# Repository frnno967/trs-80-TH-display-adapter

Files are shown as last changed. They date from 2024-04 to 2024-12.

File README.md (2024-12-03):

# Digital Video Display Adapter for the TRS-80 Model 3 and Model 4
A through-hole remix of [Matt Boytim's TRS-80 FPGA Digital Video display adapter.](https://github.com/maboytim/TRS-80_Display_Adapter/tree/main) Created with EasyEDA.

This remix removes the unused VGA connections, adds some useful powering options, adds additional silkscreen descriptions, and uses all through-hole parts for ease of assembly by the hobbyist.



# Minimum Required parts:
* QTY 1 Tang Nano 9K FPGA board with headers and programmed with bitstream from above for the appropriate Model, either 3 or 4.
* QTY 2 24 Pin Female to Male 2.54mm headers for attaching Tang Nano 9K to the PCB
* QTY 2 2 Position Male to Male 2.54mm Pin Headers for use with J3 and J5
* QTY 1 3 Position Male to Male 2.54mm Pin Headers for use with H1
* QTY 3 2.54mm Jumper Shunts like TE Connectivity 2-881545-2
* QTY 1 Texas Instruments SN74LV125AN Quad Bus Buff Gate With 3-State Outputs, or equivalent for U1. 
* QTY 1 L7805 Linear Voltage Regulator, or equivalent DC/DC voltage converter regulator for U3
* QTY 1 10uF Capacitor, Radial Leads for C1
* QTY 2 1uF Capacitor, Radial Leads for C3 and C4
* QTY 1 0.1uF Capacitor, Radial Leads for C2
* QTY 2 Axial 1K Ohm 1/4 Watt Resistors for R6 and R7

Mouser Cart with all parts available here: https://www.mouser.com/ProjectManager/ProjectDetail.aspx?AccessID=4506e6a91b

# Additional Optional Parts:
* QTY 2 6 Position Male to Male 2.54mm Pin Headers for use with Video Input from Motherboard for direct connection without the CRT Harness, with pass-through connector option to continue using the harness and output adapter at the same time.
* QTY 1 16 Pin 2x8 Male to Male 2.54mm Pin Headers for use with J4 Option Jumpers for color settings
* QTY 1 Molex 22-05-1042 Male Right Angle 4 Pin Header for power via system power supply, or for use as pass-thru power. Do not operate power-hungry devices off of 5V output of this connector!

Special thanks to Matt Boytim and all of the TRS-80 community for creating awesome enhancements like these.

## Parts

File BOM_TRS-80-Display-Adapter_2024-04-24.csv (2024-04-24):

ID | Name | Designator | Footprint | Quantity | Manufacturer Part | Manufacturer | Supplier | Supplier Part | Price | Pins | Contributor | JLCPCB Part Class | link
1 | 10uF | C1 | CAP-TH_BD6.3-P2.50-D0.5-FD | 1 | ESK106M1HD11RRSNP-R | MAN YUE(万裕科技) | LCSC | C3015490 | 0.027 | 2 | lcsc
2 | 100nF | C2 | CAP-TH_BD5.0-P2.00-D0.8-FD | 1 | 0.1uF 50V 5*11 | null | LCSC | C45091 | 0.01 | 2 |  | Extended Part
3 | 1uF | C3,C4 | CAP-TH_BD6.3-P2.50-D1.0-FD | 2 | KM105M250E11RR0VH2FP0 | CX(承兴) | LCSC | C46084 | 0.03 | 2 |  | Extended Part
4 | 22051042 | CN1 | CONN-TH_4P-P2.50_22051042 | 1 | 22051042 | MOLEX | LCSC | C588977 | 0.213 | 4 | LCSC | Extended Part | https://lcsc.com/eda_search?q=C588977&%26type=1&ref=editor
5 | VID SOURCE SELECT | H1 | HDR-TH_3P-P2.54-V-M-1 | 1 | 2.54-1*3P针 | BOOMELE(博穆精密) | LCSC | C49257 | 0.014 | 3 |  | Extended Part
6 | MB VID SOURCE | H2 | HDR-TH_6P-P2.54-V-M-1 | 1 | 2.54-1x6P直针 | BOOMELE(博穆精密) | LCSC | C37208 | 0.026 | 6 |  | Extended Part
7 | VID PASS-THRU | H3 | HDR-TH_6P-P2.54-V-M-1 | 1 | 2.54-1x6P直针 | BOOMELE(博穆精密) | LCSC | C37208 | 0.026 | 6 |  | Extended Part
8 | VID FROM CRT CONNECTOR | J1 | TRS-80 CRT CARD EDGE | 1 |  |  |  |  |  | 10 | JoshuaFireseed
9 | HDR-M-2.54_2x2 | J2 | HDR-M-2.54_2X2 | 1 |  |  | LCSC | C66690 | 0.021 | 4 | LCEDA_Lib
10 | TEST JUMPER | J3 | HDR-TH_2P-P2.54-V-M-1 | 1 | 826629-2 | TE Connectivity(泰科电子) | LCSC | C86471 | 0.377 | 2 |  | Extended Part
11 | OPTIONAL SETTINGS JUMPERS | J4 | HDR-TH_16P-P2.54-V-M-R2-C8-S2.54 | 1 | 2.54-2*8P针 | BOOMELE(博穆精密) | LCSC | C68234 | 0.07 | 16 |  | Extended Part
12 | PWR DISABLE FOR USB PROGRAMMING | J5 | HDR-TH_2P-P2.54-V-M-1 | 1 | 826629-2 | TE Connectivity(泰科电子) | LCSC | C86471 | 0.377 | 2 |  | Extended Part
13 | CMF501K0000FHEA | R6,R7 | CMF501K0000FHEA | 2 | CMF501K0000FHEA |  |  |  |  | 2 | Shant Centistoke
14 | SN74LV125AN | U1 | PDIP-14_L19.3-W6.4-P2.54-LS7.9-BL-1 | 1 | SN74LV125AN | TI(德州仪器) | LCSC | C1548088 | 1.798 | 14 | LCSC | Extended Part
15 | L7805CV | U3 | TO-220-3_L10.0-W4.5-P2.54-L | 1 | L7805CV | ST(意法半导体) | LCSC | C111887 | 0.197 | 3 |  | Extended Part
16 | TANGNANO9K_PCB_ | U5 | TANGNANO9K | 1 |  |  | LCSC |  |  | 48 | Михаил Голяков

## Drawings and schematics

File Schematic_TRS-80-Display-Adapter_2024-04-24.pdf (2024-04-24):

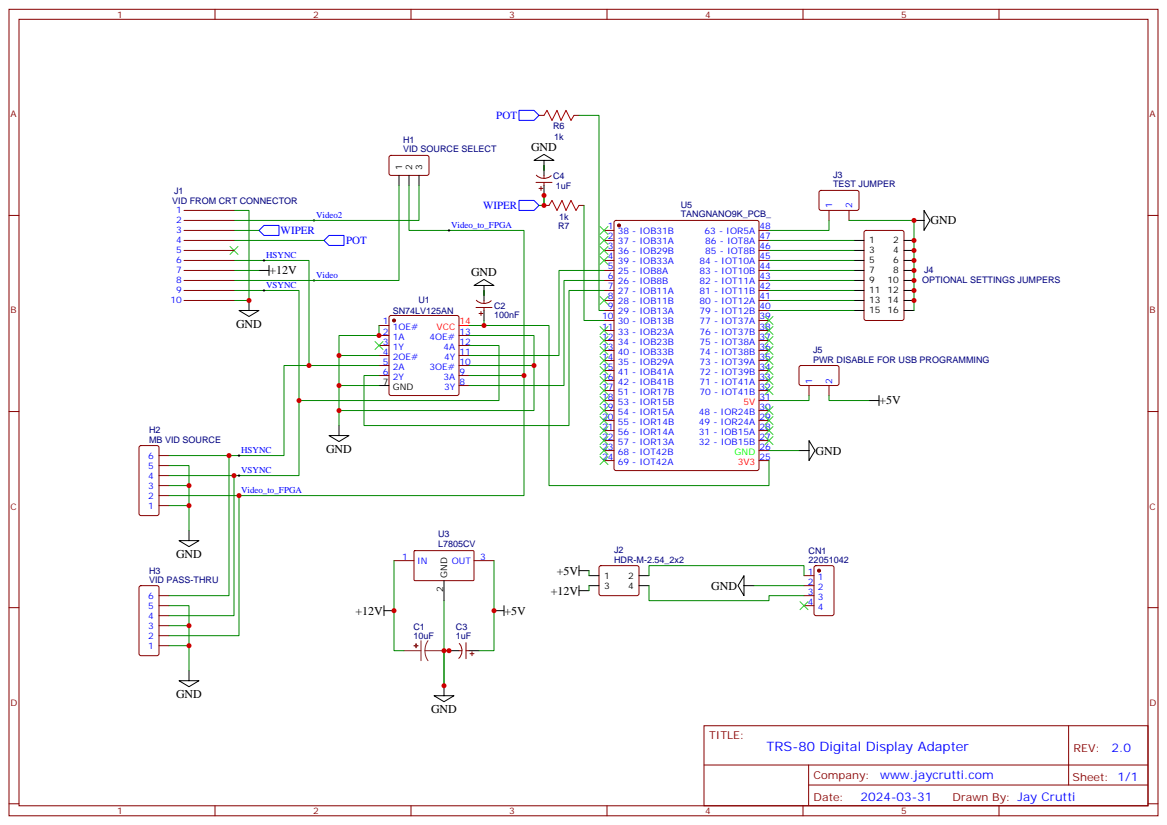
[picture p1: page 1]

PWR DISABLE FOR USB PROGRAMMING

Company: www.jaycrutti.com

Drawn By: Jay Crutti

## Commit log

2024-02-01 Revert "Add files via upload"
    This reverts commit 786acf0cb42d98abf2844d2c8efa01b0954695ed.
    [BOM_TRS-80-Display-Adapter_2024-01-31 (1).csv, BOM_TRS-80-Display-Adapter_2024-01-31.csv, PCB_TRS-80-Display-Adapter_2024-01-31.dxf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]
2024-02-02 Added U1 to BOM
    Added mention of U1
2024-02-12 Update to final rev
    [BOM_TRS-80-Display-Adapter_2024-02-01.csv, BOM_TRS-80-Display-Adapter_2024-02-12.csv, TRS-80-Digital-Display-Adapter-Schematic_2024-02-01.schdoc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]
2024-02-12 correct routing
    [TRS-80-Digital-Display-Adapter_2024-02-12.dxf, TRS-80-Digital-Display-Adapter_2024-02-12.pcbdoc]
2024-02-12 update silkscreen
    [TRS-80-Digital-Display-Adapter_2024-02-12.dxf, TRS-80-Digital-Display-Adapter_2024-02-12.pcbdoc]
2024-04-24 updated Gerbers
    [TRS-80-Digital-Display-Adapter_2024-02-12.dxf, TRS-80-Digital-Display-Adapter_2024-02-12.pcbdoc, TRS-80-Digital-Display-Adapter_2024-04-24.pcbdoc]
2024-04-24 updated schematic
    [BOM_TRS-80-Display-Adapter_2024-02-12.csv, BOM_TRS-80-Display-Adapter_2024-04-24.csv, TRS-80-Digital-Display-Adapter-Schematic_2024-02-12.schdoc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]
